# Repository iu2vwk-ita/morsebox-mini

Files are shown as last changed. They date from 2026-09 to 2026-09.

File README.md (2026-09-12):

# MorseBox Mini — WiFi CW Trainer

A Morse keyer in a box. It serves a web page over its own WiFi: join the
network, open the page, key with a real paddle or the touch paddle on screen,
and read back your keying as text. The sidetone comes straight off the GPIO
pins with zero lag, on up to three piezo buzzers at once.

Two builds, **the same features and the same web UI**:

| Build | Folder | Board | Display |
|---|---|---|---|
| **Raspberry Pi** | root (`server.py`, `install.sh`, …) | Pi 4 / 5 / Zero 2 W | MAX7219 8x8 (optional) |
| **ESP32 / MicroPython** | [`esp32/`](esp32/) | classic ESP32 (also C3/C6/S3 with small pin changes) | SSD1306 OLED or LCD1602 I2C (optional) |

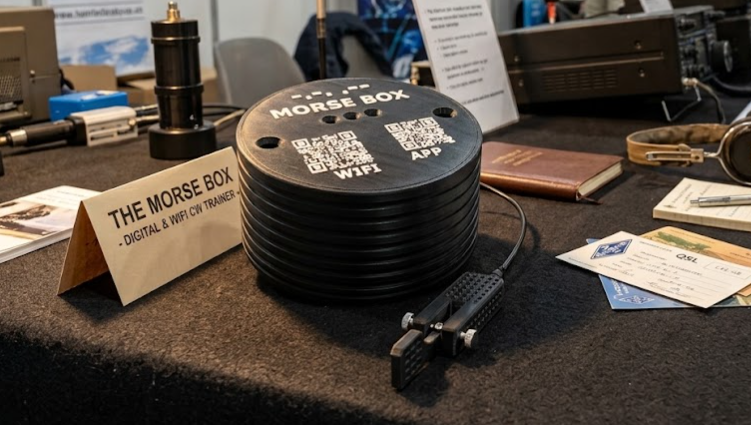
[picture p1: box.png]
MorseBox assembled


## Quick install

**Raspberry Pi** (Raspberry Pi OS) — one command:

```bash
sudo apt install -y git && git clone https://github.com/iu2vwk-ita/morsebox-mini.git morsebox && cd morsebox && sudo bash install.sh
```

**ESP32 / MicroPython** — one command (first: `pip install mpremote`):

```bash
git clone https://github.com/iu2vwk-ita/morsebox-mini.git && cd morsebox/esp32 && bash deploy.sh
```

## What it does

* Iambic A / B, straight key and a **SINGLE** beginner mode (one tap = one
  element, no memory/repeat), 5 to 60 WPM, paddle reverse (DX⇄SX)
* Live decoded text on the web page and on the display
* Sidetone pitch (500–1000 Hz) and volume from the page, on 1 to 3 piezos;
  **Active / Passive buzzer** selector (active buzzer or passive piezo)
* Key with a paddle, a straight key, the on-screen paddle, or the keyboard
  (`Z` / `X` / space)
* **Exercise mode / CW courses** — a built-in trainer (see below)
* **Reflex Trainer game** — 40 random characters, adaptive speed, countdown
  timer (menu item 1)

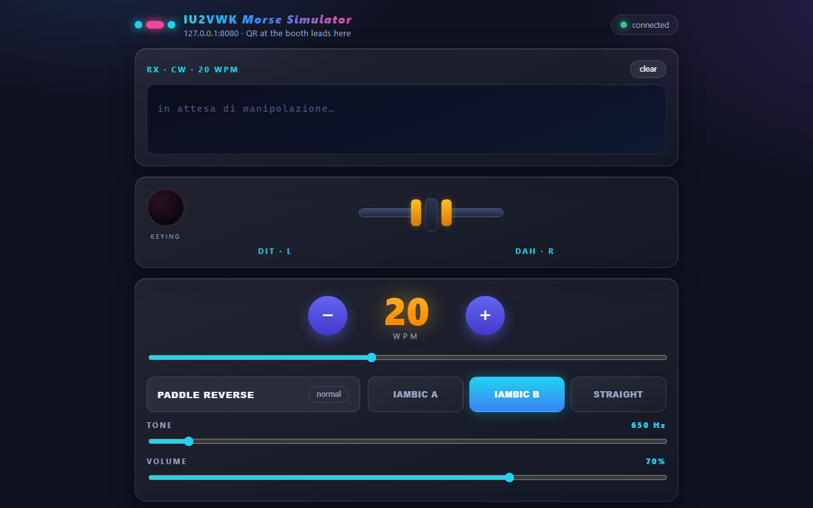
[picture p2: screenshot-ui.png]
Web UI


## Exercise mode (CW courses)

A guided trainer, available on **both** builds. Open the menu by keying **SOS**,
pick a drill with **N dots**, then confirm with **`..`** (or exit with `--`).
The target is **shown on the display and played on the piezo** at the chosen
WPM; for multi-letter targets the whole word is shown and the letter to key
**blinks**. A correct letter **flashes** as confirmation.

| N dots | Name on LCD | What |
|---|---|---|
| `.` | GAME | Reflex Trainer (see below) |
| `..` | ALPHABET | Alphabet A-Z |
| `...` | NUMBERS | Numbers 0-9 |
| `....` | KOCH | Koch order |
| `.....` | LETTERS | 20 random letters |
| `......` | DIGITS | 20 random digits |
| `.......` | MIXED | 20 random mixed letters/digits |
| `........` | CALLSIGNS | Common callsigns |
| `.........` | ABBREV | Q-codes / abbreviations |
| `..........` | PUNCT | Punctuation / prosigns |
| `-` | FULL | Full drill: A-Z then 0-9 |

While you key the menu selection the keyer runs slowly (**10 WPM**) so the dots
are easy to count; once a drill starts it uses your normal WPM setting. When you
pick a number the display shows its name (e.g. `4 KOCH ?`) before you confirm
with `..`, so the mapping is always visible on the device.

### Reflex Trainer (game)

Key **`SOS`** then **one dot** (or key the word `GAME`) to play. The box plays a
random character and you key it back before the timer bar runs out:

* correct -> **+1 point**, speed **+1 WPM**
* wrong or too slow -> **lose a life**, speed **-2 WPM**

It adapts to your level (10-40 WPM). You start with 3 lives; the display shows
`S:score L:lives WPM` and the countdown bar. Key **6 dots** to stop.

During a drill: **`......`** (6 dots, one group) = **stop**,
**`------`** (6 dashes, one group) = **skip**. A correct answer advances, a
wrong one restarts the target; the run ends with `DONE n/m`. You can also start
directly with `TEST` (full drill) or `TEST1`..`TEST9`.

## Open the web UI

The board is the access point. No home router, no internet needed.

1. Power the box, wait a few seconds
2. Join the WiFi **`IU2VWK-MORSE`** (password `morse1234`). The phone will say
   "connected without internet": that is normal, stay on it
3. Open **`http://10.42.0.1`**

The lid has two QR codes: **WIFI** joins the network, **APP** opens the page.
At home the Raspberry Pi version also works over Ethernet on port 80.

## Raspberry Pi — hardware and wiring

* Raspberry Pi (4, 5, Zero 2 W or similar) with Raspberry Pi OS Lite
* Paddle or straight key wired to the GPIO header (contacts to GND, internal
  pull-ups, no extra parts)
* 1 to 3 passive piezo buzzers (KY-006 3-pin modules)
* Optional MAX7219 8x8 LED matrix (shows WPM plus live decoded text)

| Function | BCM GPIO | Header pin |
|---|---|---|
| DIT (paddle) | 17 | 11 |
| DAH (paddle) | 27 | 13 |
| Straight key | 22 | 15 |
| GND | — | 6, 9, 14… |
| Piezo 1 signal | 24 | 18 |
| Piezo 2 signal | 25 | 22 |
| Piezo 3 signal | 12 | 32 |
| MAX7219 DIN / CLK / CS | 10 / 11 / 8 | 19 / 23 / 24 |

Each KY-006 module: `S` to its signal pin, `+` (middle) to 5V, `−` to GND. All
`5V` pins are one rail and all `GND` pins are one rail, so power wires can
share. Default buzzer mode is `passive`; with a self-beeping active buzzer use
`--buzzer-mode active`.

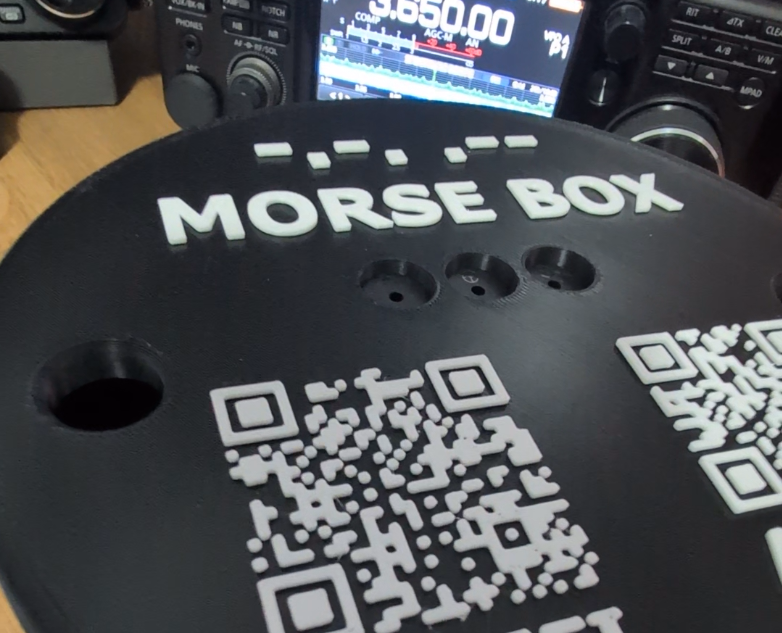
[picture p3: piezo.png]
The three piezos wired in


Install (the one-liner above does all of this): it sets the hostname to
`iu2vwk-morse`, installs the autostart service and brings up the
`IU2VWK-MORSE` access point. Three buzzers:

```bash
# /etc/systemd/system/iu2vwk-morse.service
ExecStart=/usr/bin/python3 /opt/iu2vwk-morse/server.py --port 80 --buzz-pins 24,25,12
sudo systemctl daemon-reload && sudo systemctl restart iu2vwk-morse
```

## ESP32 / MicroPython — hardware and wiring

Code in [`esp32/`](esp32/), full guide in
[`esp32/README-ESP32.md`](esp32/README-ESP32.md) (flashing, LCD1602, wiring).

| Function | GPIO |
|---|---|
| DIT | 32 |
| DAH | 33 |
| STRAIGHT | 14 |
| PIEZO 1 / 2 / 3 | 25 / 26 / 27 |
| I2C SDA / SCL (OLED or LCD1602) | 21 / 22 |
| MAX7219 SCK / MOSI / CS | 18 / 23 / 4 |

Key contacts to GND, internal pull-ups. The firmware auto-detects the display
at boot: **SSD1306 OLED first, then LCD1602, then MAX7219, then none**. Both
I2C displays share the same two wires:

* **SSD1306 OLED** (0.96"/1.3", 128x64, I2C 4-pin) — the nicest option: ~5-6
  lines of text, no cramped 16x2 window. `VCC` to **3.3V**, `GND`, `SCL` to
  GPIO22, `SDA` to GPIO21. Address 0x3C/0x3D (auto-detected).
* **LCD1602** with I2C backpack — `VCC` to 5V (VIN), `GND`, same SDA/SCL.
  Address 0x27/0x3F.

### Display options (pick one, or none)

The firmware detects the display automatically, in this order:
**SSD1306 OLED -> LCD1602 -> MAX7219 -> no display**. Nothing to configure.

* **With SSD1306 OLED** (recommended — "the nice one") — 128x64 graphical
  display, same two I2C wires as the LCD. Top line `WPM xx` + keyer mode, then
  the decoded text wrapped over several lines; the exercise target and its `^`
  cursor are far easier to read. The driver is loaded **only** if the I2C bus
  answers at 0x3C/0x3D, so with no OLED there is no RAM cost.

* **With LCD1602** — line 1 `WPM xx` + keyer mode, line 2 the decoded text.

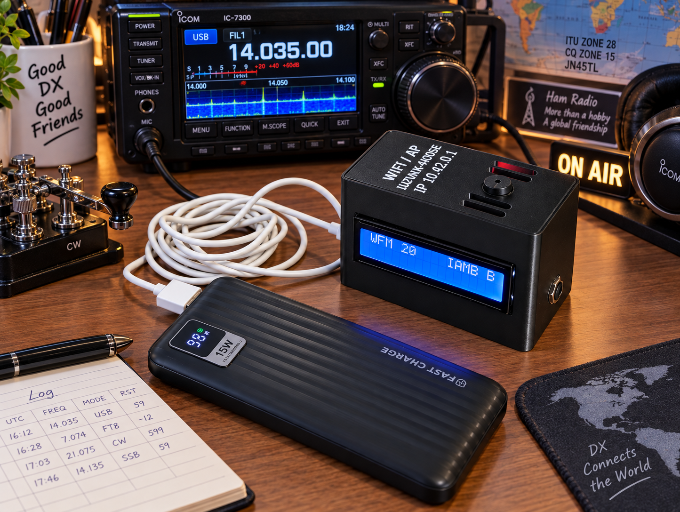
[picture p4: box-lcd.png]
MorseBox ESP32 with LCD1602
  

* **Without display (simpler)** — no display: everything is controlled from the
  phone web app (speed, mode, tone, volume and the decoded text). This is the
  easiest build.

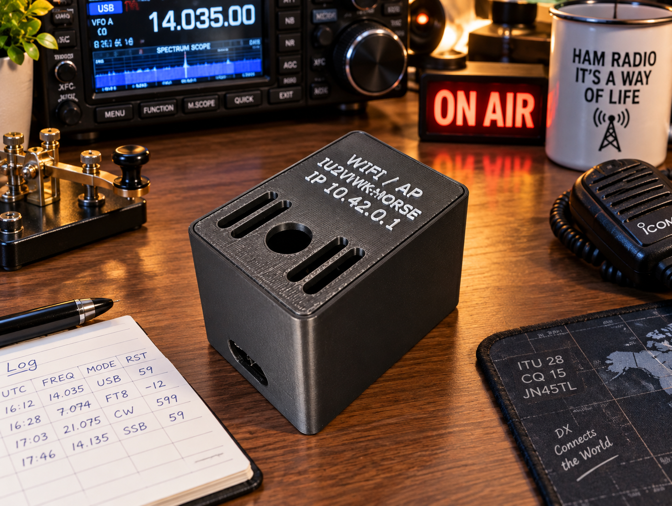
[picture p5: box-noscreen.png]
MorseBox ESP32 without LCD
  

## Box and fair material

* `qr-1-wifi.png` / `qr-2-pagina.png` — the **WIFI** and **APP** QR codes for
  the lid
* `qr-1-wifi.dxf` / `qr-2-pagina.dxf` — same QRs as 2 mm geometry for laser
  engraving in Autodesk Inventor
* `screenshot-ui-phone.png` — how the page looks on a phone
* `CW BOX SMALL.3mf` — the box, ready to 3D print, all versions on separate
  plates: ESP32 with LCD, ESP32 without LCD, and Raspberry Pi

73 de IU2VWK · Angelo — https://iu2vwk.com

Thanks to Panko for the inspiration and the original
[Simple CW Keyer](https://github.com/Panko74/Simple-CW-Keyer).

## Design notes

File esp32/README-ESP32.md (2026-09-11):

# MorseBox Mini - ESP32 / MicroPython version

Port of the Raspberry Pi version to a classic **ESP32** with **MicroPython**.
The web UI is **identical** to the Pi one: the same `static/index.html`,
`static/style.css`, `static/app.js` files are served unchanged, and the
WebSocket protocol is the same.

## What it does

- The ESP32 creates the access point **`IU2VWK-MORSE`** (password `morse1234`).
- HTTP + WebSocket web server on port **80**, IP **10.42.0.1**
  (same IP as the Pi: the lid QR codes keep working).
- Iambic A / B + straight keyer + **SINGLE** beginner mode (one tap = one
  element, no memory/repeat), 5-60 WPM, reverse DX/SX, CW to text decoder.
- **Zero-latency hardware PWM sidetone** on 1-3 piezos, no audio pipeline.
- Optional display, **auto-detected at boot**: SSD1306 OLED -> LCD1602 I2C ->
  MAX7219 8x8 -> none. The **OLED** (128x64, recommended) shows `WPM xx` +
  keyer mode on the top line and the decoded CW text wrapped below; the LCD
  shows 16x2. No RAM cost when no OLED is connected.

## Exercise mode

**Beginner-friendly start:** key **`SOS`** (`...---...`) to open the exercise
menu, key **N dots** to pick a drill, then **`..`** to confirm (or **`--`** to
exit). The target is **shown on the LCD and played on the piezo** (always
together) at the selected WPM, then you key it back.

| N dots | Name on LCD | Exercise |
|---|---|---|
| `.` | GAME | Reflex Trainer (see below) |
| `..` | ALPHABET | TEST1 - Alphabet A-Z |
| `...` | NUMBERS | TEST2 - Numbers 0-9 |
| `....` | KOCH | TEST3 - Koch order |
| `.....` | LETTERS | TEST4 - 20 random letters |
| `......` | DIGITS | TEST5 - 20 random digits |
| `.......` | MIXED | TEST6 - 20 random mixed |
| `........` | CALLSIGNS | TEST7 - Common callsigns |
| `.........` | ABBREV | TEST8 - Q-codes / abbreviations |
| `..........` | PUNCT | TEST9 - Punctuation / prosigns |
| `-` | FULL | Full drill: A-Z then 0-9 |

While you key the menu selection the keyer runs slowly (**10 WPM**,
`config.MENU_WPM`) so the dots are easy to count; once a drill starts it uses
the normal WPM setting. When you pick a number the LCD shows its name (e.g.
`4 KOCH ?`) before you confirm with `..`.

### Reflex Trainer (game)

Key **`SOS`** then **one dot** (or key `GAME`) to play. A random character is
played and you key it back before the timer bar runs out: correct = +1 point
and +1 WPM, wrong/too slow = -1 life and -2 WPM (10-40 WPM, 3 lives). The LCD
shows `S:score L:lives WPM` and the countdown bar. Key **6 dots** to stop.

You can also key **`TEST`** (full drill) or **`TEST1`..`TEST9`** directly.

Controls: **`......`** (6 dots) = stop, **`------`** (6 dashes) = skip. A
correct answer advances; a wrong one repeats the same target. The end of the
run shows `DONE n/m`.

## Pinout

| Function | GPIO | Mode |
|---|---|---|
| DIT | 32 | `Pin.IN, PULL_UP` (contact to GND) |
| DAH | 33 | `Pin.IN, PULL_UP` (contact to GND) |
| STRAIGHT | 14 | `Pin.IN, PULL_UP` (contact to GND) |
| PIEZO 1 | 25 | `machine.PWM` |
| PIEZO 2 | 26 | `machine.PWM` |
| PIEZO 3 | 27 | `machine.PWM` |
| MAX7219 SCK | 18 | hardware SPI VSPI |
| MAX7219 MOSI | 23 | hardware SPI VSPI |
| MAX7219 CS | 4 | output |
| I2C SDA (OLED / LCD1602) | 21 | I2C |
| I2C SCL (OLED / LCD1602) | 22 | I2C |

The three piezos sound together: even one is enough.
The key contacts go to GND; the pull-ups are internal to the ESP32.

**Display** (optional, auto-detected: **OLED -> LCD1602 -> MAX7219 -> none**).
Both I2C displays use the same two wires:

- **SSD1306 OLED** (0.96"/1.3", 128x64, I2C **4-pin**): `VCC` to **3.3V**,
  `GND`, `SCL` to GPIO22, `SDA` to GPIO21. Address 0x3C/0x3D, scanned
  automatically. This is the nicest option.
- **LCD1602** with I2C backpack: `VCC` to 5V (VIN), `GND`, same SDA/SCL
  (address 0x27/0x3F).

## Requirements

- ESP32 (WROOM-32) with recent MicroPython firmware (>= 1.20).
- `mpremote` on the PC: `pip install mpremote`.

If the ESP32 has no MicroPython, flash it with esptool:

```bash
esptool.py --chip esp32 --port /dev/ttyUSB0 erase_flash
esptool.py --chip esp32 --port /dev/ttyUSB0 write_flash -z 0x1000 \
  ESP32_GENERIC-20240602-v1.23.0.bin
```

## Deploy

```bash
bash deploy.sh                 # auto port
bash deploy.sh /dev/ttyUSB0    # explicit port
```

The script copies the `.py` files to the ESP32 root, creates `/static` with the
web UI and resets the board. On boot `main.py` starts.

## Test (no hardware)

The logic can be verified on a PC with CPython, using `uasyncio`/`time` stubs:

```bash
python3 tests/test_all.py
```

It covers: iambic A/B keyer, single mode, reverse, straight, decoder, WebSocket handshake,
frame encode/decode, HTTP parsing, routes and path traversal.

## Usage

1. Power the board, wait a few seconds.
2. On your phone, join the Wi-Fi **`IU2VWK-MORSE`** (password `morse1234`).
   The phone will say "no internet": that is normal, stay on that network.
3. Open **`http://10.42.0.1`**.
4. Key with the paddle, the straight key, the touch paddles or the keyboard
   (`Z` / `X` / space bar).

## Configuration

In `config.py`:

- `OLED_ENABLED = True` to use an SSD1306 I2C OLED (default `True`, tried
  first). The `oled` module is imported only if the bus answers at 0x3C/0x3D,
  so there is **no RAM cost** when no OLED is connected.
- `LCD_ENABLED = True` to use the LCD1602 I2C display (default `True`).
- `DISPLAY_ENABLED = True` to use the MAX7219 matrix (default `False`).
- `BUZZER_MODE = "passive"` for piezos (default). `"active"` for buzzers with
  a built-in oscillator (DC on/off drive).
- `AP_SSID` / `AP_PASS` / `AP_IP` to change the network.

The WPM, tone, volume, mode and reverse settings are saved in `settings.json`
and persist across reboots.

## Module reference

| Module | Main entry points | What it does |
|---|---|---|
| `main.py` | `main()` | Boot: AP, settings, paddle, piezo, display, event loop |
| `config.py` | constants | Pin map, defaults, boot messages |
| `wifi_ap.py` | `start_ap()` | Creates the `IU2VWK-MORSE` access point |
| `gpio.py` | `Paddle.read()` | Reads DIT / DAH / STRAIGHT (active low, pull-up) |
| `sidetone.py` | `Sidetone.set()`, `set_freq()`, `set_volume()` | Zero-latency PWM on 1-3 piezos |
| `keyer.py` | `Keyer.run()` | Iambic A/B + straight + single state machine and CW decoder |
| `keyer.py` | `_set_key()`, `_flush_letter()`, `_check_exercise_trigger()`, `_menu_select()` | Key output, letter decoding, exercise triggers and menu |
| `exercise.py` | `build(n)` | Builds the target list for drill `n` (0..9) |
| `exercise.py` | `Exercise.enter_menu()`, `select()`, `confirm()`, `cancel()`, `start()`, `feed()`, `run()` | Menu, confirmation, per-letter progress, blinking target, playback |
| `reflex.py` | `Reflex.run()`, `start()`, `feed()` | Reflex Trainer game: random target, countdown timer, adaptive WPM |
| `hub.py` | `Hub.broadcast()`, `remote()`, `hold()` | WebSocket clients, remote paddle holds, text history |
| `wsproto.py` | `ws_accept()`, `ws_encode()`, `ws_read_frame()` | Minimal RFC 6455 WebSocket |
| `webserver.py` | `WebServer.start()` | HTTP routes + WebSocket upgrade (native sockets) |
| `oled.py` | `Screen` | SSD1306 128x64 OLED: WPM/mode, wrapped decoded text, exercise target |
| `ssd1306.py` | `SSD1306_I2C` | MicroPython SSD1306 I2C driver (micropython-lib, MIT) |
| `lcd1602.py` | `I2cLcd`, `Screen` | 16x2 I2C display: WPM/mode, decoded text, exercise target |
| `display.py` | `Max7219`, `Screen` | Optional 8x8 matrix (scrolling text) |
| `settings.py` | `Settings.get()`, `patch()` | Persistent settings on `settings.json` |
| `morse.py` | `MORSE`, `FROM_MORSE` | Morse table and its reverse |
| `tests/test_all.py` | — | Host-side tests (CPython, `uasyncio`/`time`/`machine`/`ssd1306` stubs) |
| `tests/selftest_device.py` | — | On-device self-test: AP, GPIO, PWM, HTTP, WS, keyer |

## Differences from the Pi version

| | Raspberry Pi | ESP32 MicroPython |
|---|---|---|
| Concurrency | threads | single `uasyncio` event loop |
| Web server | `http.server` + custom WS | native `uasyncio` sockets + custom WS |
| AP | hostapd + dnsmasq | native `network.WLAN(AP_IF)` |
| AP IP | 10.42.0.1 | 10.42.0.1 |
| mDNS hostname | `iu2vwk-morse.local` | not available (use the IP) |
| Deploy | `install.sh` + systemd | `deploy.sh` + `main.py` |
| Mic audio decoder | yes (optional) | **no** (dropped) |

## Technical notes

- The keyer runs at a ~1 ms tick and uses `time.ticks_ms()`: loop jitter does
  not accumulate, because every element is computed from the current instant.
- The sidetone is switched directly by the key state through `machine.PWM`:
  no audio buffer, no perceivable delay.
- `hub.broadcast()` never blocks the keyer: every WebSocket client has a queue;
  a slow client is dropped without stopping the key.

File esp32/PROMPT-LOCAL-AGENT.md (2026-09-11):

# Prompt to paste into a local AI agent (with filesystem and USB access)

You are an AI agent with access to this PC's filesystem and USB ports.
You must install MicroPython on an ESP32 board connected over USB, upload the
project inside `morsebox-esp32.zip` and run the automated tests.
Do not ask for confirmation for the commands: run them and report the result.
If a command fails, diagnose it and try the suggested alternatives.

## Project

- Folder `morsebox-esp32/` (inside the zip).
- MicroPython app: on boot `main.py` creates the access point
  **`IU2VWK-MORSE`** (password `morse1234`), IP **10.42.0.1**, web server on
  port **80**.
- Pinout: **DIT=GPIO32**, **DAH=GPIO33**, **STRAIGHT=GPIO14** (all `Pin.IN`
  with `PULL_UP`, contacts to GND); **PIEZO=GPIO25,26,27** (PWM); MAX7219
  optional on **SCK=18, MOSI=23, CS=4** (disabled by default); LCD1602 I2C on
  **SDA=21, SCL=22**.
- `static/` is the web UI: **do not modify it**.
- `tests/selftest_device.py` is the test that runs **on the board**.

## Phase 0 - extract and prepare the tools

```bash
unzip morsebox-esp32.zip
cd morsebox-esp32
python3 -m venv .venv && . .venv/bin/activate
pip install esptool mpremote
```

## Phase 1 - detect serial port and chip

```bash
# Linux
ls /dev/ttyUSB* /dev/ttyACM*
# macOS
ls /dev/cu.*
# detect the chip (replace <PORT>)
esptool.py --port <PORT> chip_id
```

If no port appears: change the cable (it must be a **data** cable, not
charge-only), try another USB port, or use a USB-TTL adapter on TX/RX/GND.
On Linux, if permission is denied: `sudo chmod a+rw <PORT>` or add the user to
the `dialout` group.

## Phase 2 - flash MicroPython

Pick the firmware based on the detected chip:

- Classic ESP32 -> `ESP32_GENERIC`
- ESP32-S3 -> `ESP32_GENERIC_S3`
- ESP32-C3 -> `ESP32_GENERIC_C3`

Download the latest `.bin` from <https://micropython.org/download/> and then:

```bash
esptool.py --chip esp32 --port <PORT> erase_flash
esptool.py --chip esp32 --port <PORT> --baud 460800 write_flash -z 0x1000 <firmware>.bin
```

If flashing fails, hold **BOOT** while connecting the board and retry.
Adapt `--chip` to the real chip (`esp32`, `esp32s3`, `esp32c3`).

## Phase 3 - deploy the project

```bash
bash deploy.sh <PORT>
```

Check the board contents:

```bash
mpremote connect <PORT> fs ls
mpremote connect <PORT> fs ls :static
```

## Phase 4 - on-device self-test

Disable autostart (so the REPL and port 80 are free), run the test, then
restore `main.py`:

```bash
mpremote connect <PORT> fs cp main.py :main.py.bak
mpremote connect <PORT> fs rm :main.py
mpremote connect <PORT> reset
sleep 3
mpremote connect <PORT> run tests/selftest_device.py
mpremote connect <PORT> fs cp main.py.bak :main.py
mpremote connect <PORT> fs rm :main.py.bak
mpremote connect <PORT> reset
```

Expect a sequence of `PASS` lines and at the end:

```
PASS: N   FAIL: 0
```

The test checks: AP active and IP `10.42.0.1`, GPIO read at idle, PWM on/off
and frequency, HTTP (`/`, `/style.css`, `/app.js`, `/api/settings`, 404),
WebSocket (101 + `hello`) and **Morse decoding driven by remote paddles**
(dit + dah -> `A`).

## Phase 5 - final report

Report concisely:

- serial port used and detected chip;
- MicroPython firmware used;
- full self-test output;
- any `FAIL` with its cause;
- confirmation that after the final reset the `IU2VWK-MORSE` AP is active.

## Success criteria

1. MicroPython installed and `main.py` restored (starts on boot).
2. Self-test with `FAIL: 0` (or every FAIL explained).
3. `IU2VWK-MORSE` AP active after the reset.

## What cannot be tested without hardware

- The physical paddle/straight key contacts and the real piezo sound.
- The MAX7219 display if not connected.

## Notes

- If the PC has no Wi-Fi it cannot join the AP: the self-test uses the board's
  own loopback (`127.0.0.1`), so it works anyway.
- Do not modify the files in `static/`: the UI must stay identical to the
  original.

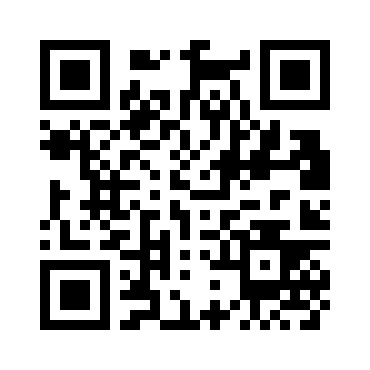
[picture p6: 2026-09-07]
qr-1-wifi.png

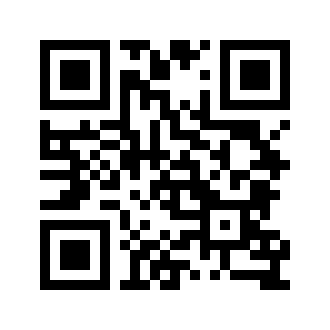
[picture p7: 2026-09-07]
qr-2-pagina.png

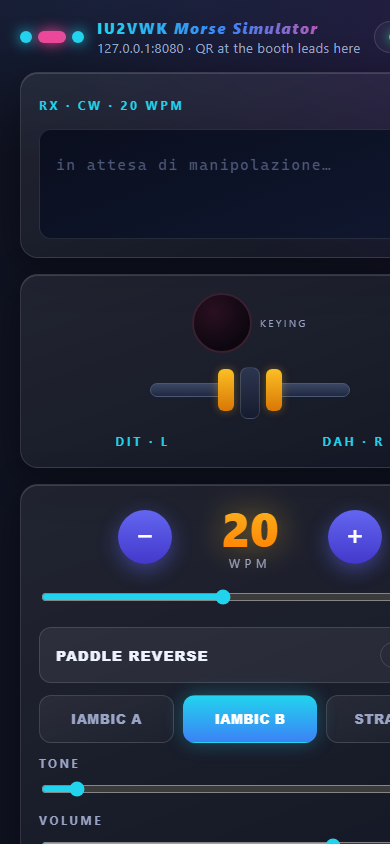
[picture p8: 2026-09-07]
screenshot-ui-phone.png

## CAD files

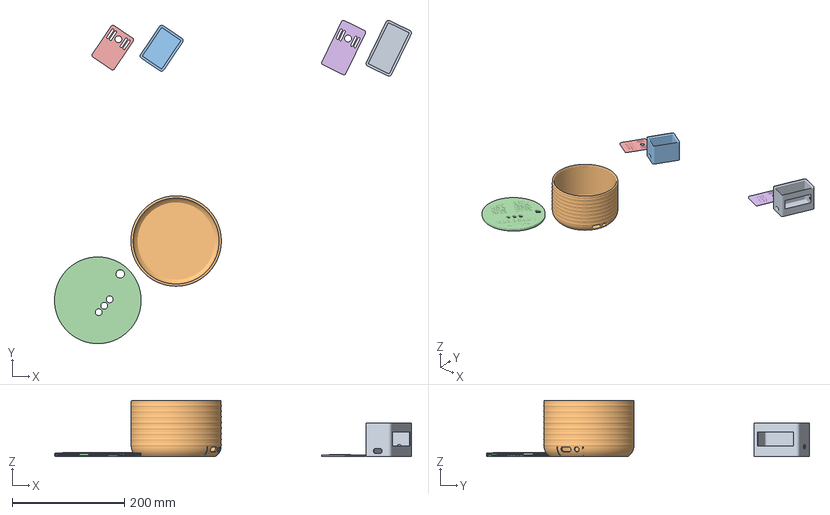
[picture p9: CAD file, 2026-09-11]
CW BOX SMALL.3mf
636.1 x 575.9 x 100.0 mm
cw box small sotto_CPY
cw box small sotto
cw box small coperchio
cw box small coperchio_CPY

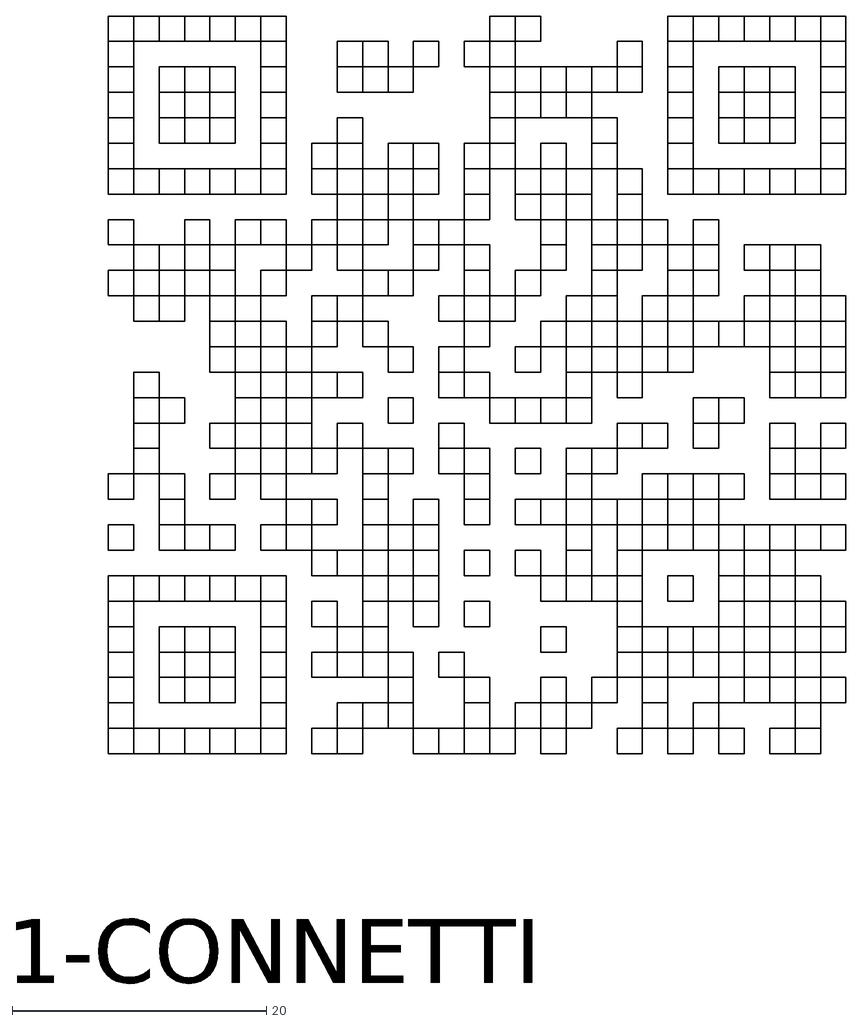
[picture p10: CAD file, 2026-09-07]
qr-1-wifi.dxf
1-CONNETTI

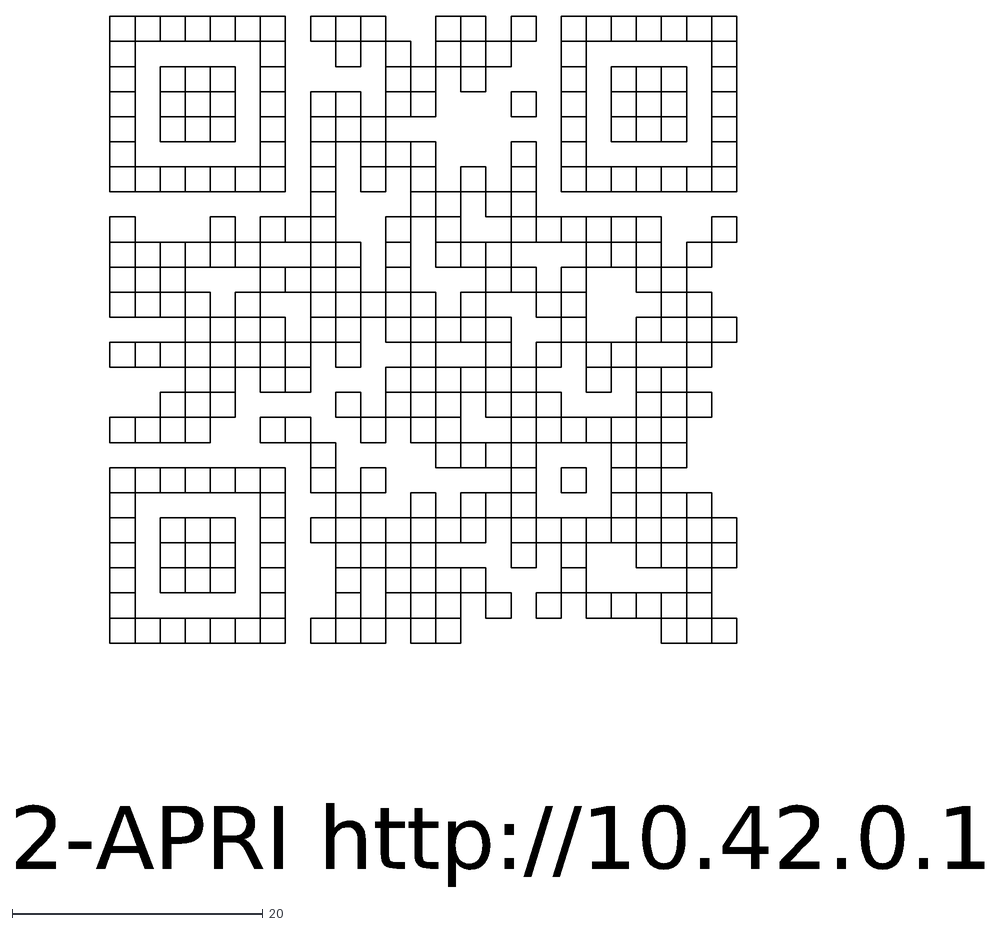
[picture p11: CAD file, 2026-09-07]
qr-2-pagina.dxf
2-APRI http://10.42.0.1

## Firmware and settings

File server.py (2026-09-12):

#!/usr/bin/env python3
"""IU2VWK Morse Simulator - iambic keyer + web UI for Raspberry Pi.

- Reads the paddle/straight key from the GPIO (mock fallback outside the Pi).
- Iambic A/B keyer + straight mode, 5-60 WPM, DX/SX swap.
- Serves the web UI, exposes a WebSocket for remote (touch) keys and live events.
- Decodes CW into text. Stdlib only: nothing to install.

Wiring (BCM): DIT=GPIO17 (pin 11), DAH=GPIO27 (pin 13), STRAIGHT=GPIO22 (pin 15),
GND on pin 6/9/14. Optional active buzzer on GPIO24 (pin 18). Contacts to GND.
"""
import argparse
import base64
import hashlib
import json
import os
import struct
import threading
import time
from http.server import BaseHTTPRequestHandler, ThreadingHTTPServer
from urllib.parse import urlparse
from morse import FROM_MORSE
from exercise import Exercise
from reflex import Reflex
from easter import EasterEgg

BASE_DIR = os.path.dirname(os.path.abspath(__file__))
SETTINGS_FILE = os.path.join(BASE_DIR, "settings.json")
STATIC_DIR = os.path.join(BASE_DIR, "static")

DEFAULTS = {"wpm": 20, "reverse": False, "mode": "iambic-b",
            "tone": 650, "buzzer": False, "volume": 70,
            "buzzer_mode": "passive"}

DIT_PIN, DAH_PIN, KEY_PIN, BUZZ_PIN = 17, 27, 22, 24
HOLD_TIMEOUT = 2.5  # s: forget remote paddles that stop reporting

# While choosing a program in the SOS menu (1-10 dots) the keyer runs slowly at
# this speed. Once the drill starts it uses the normal WPM setting.
MENU_WPM = 10

# ---------------------------------------------------------------- settings
def as_bool(v, default=False):
    """Strict boolean: 'false' must NOT become True (bool('false') == True)."""
    if isinstance(v, bool):
        return v
    if isinstance(v, (int, float)):
        return v != 0
    if isinstance(v, str):
        return v.strip().lower() in ("1", "true", "yes", "on")
    return default


class Settings:
    def __init__(self):
        self._lock = threading.Lock()
        self._data = dict(DEFAULTS)
        self._last_save = 0.0
        self._dirty = False
        try:
            with open(SETTINGS_FILE, encoding="utf-8") as f:
                self._data.update(json.load(f))
        except (OSError, ValueError):
            pass
        self._clamp()
        # flush debounced saves in the background (avoids SD wear on a drag)
        threading.Thread(target=self._saver, daemon=True).start()

    def _clamp(self):
        # per-field fallback: one bad value must not wipe the others
        d = self._data
        d["wpm"] = self._int(d, "wpm", 20, 5, 60)
        d["tone"] = self._int(d, "tone", 650, 500, 1000)
        d["volume"] = self._int(d, "volume", 70, 0, 100)
        d["reverse"] = as_bool(d.get("reverse", False))
        d["buzzer"] = as_bool(d.get("buzzer", False))
        if d.get("mode") not in ("iambic-a", "iambic-b", "straight", "single"):
            d["mode"] = "iambic-b"
        if d.get("buzzer_mode") not in ("active", "passive"):
            d["buzzer_mode"] = "passive"

    @staticmethod
    def _int(d, key, default, lo, hi):
        try:
            return max(lo, min(hi, int(d.get(key, default))))
        except (TypeError, ValueError):
            return default

    def get(self):
        with self._lock:
            return dict(self._data)

    def snapshot(self):
        """Read-only view with NO copy: used by the 1 ms keyer loop."""
        return self._data

    def patch(self, p):
        with self._lock:
            for k in DEFAULTS:
                if k in p:
                    self._data[k] = p[k]
            self._clamp()
            self._dirty = True
            data = dict(self._data)
        self.flush()
        return data

    def flush(self):
        """Write at most once per second; the background thread guarantees the
        last change is eventually persisted."""
        with self._lock:
            if not self._dirty:
                return
            now = time.monotonic()
            if now - self._last_save < 1.0:
                return
            self._last_save = now
            self._dirty = False
            data = dict(self._data)
        try:
            with open(SETTINGS_FILE, "w", encoding="utf-8") as f:
                json.dump(data, f)
        except OSError:
            with self._lock:
                self._dirty = True

    def _saver(self):
        while True:
            time.sleep(0.5)
            try:
                self.flush()
            except Exception:
                pass


# ---------------------------------------------------------------- gpio
class GPIO:
    """Active-low pull-up inputs. Tries RPi.GPIO, then gpiozero, then mock."""

    def __init__(self, buzz_pins=None):
        self.backend = "mock"
        self._gpio = None
        self._dit = self._dah = self._key = None
        self._buzz = []
        # Extra buzzer pins (BCM), e.g. [24, 25]. Default: only 24 (pin 18).
        self.buzz_pins = list(buzz_pins) if buzz_pins else [BUZZ_PIN]
        try:
            import RPi.GPIO as G
            G.setmode(G.BCM)
            for p in (DIT_PIN, DAH_PIN, KEY_PIN):
                G.setup(p, G.IN, pull_up_down=G.PUD_UP)
            self._gpio = G
            self.backend = "RPi.GPIO"
        except Exception:
            try:
                from gpiozero import Button, LED
                self._dit = Button(DIT_PIN, pull_up=True)
                self._dah = Button(DAH_PIN, pull_up=True)
                self._key = Button(KEY_PIN, pull_up=True)
                self._buzz = [LED(p) for p in self.buzz_pins]
                self.backend = "gpiozero"
            except Exception:
                pass

    def read(self):
        """(dit, dah, straight) True = pressed."""
        if self._gpio is not None:
            G = self._gpio
            return (not G.input(DIT_PIN), not G.input(DAH_PIN),
                    not G.input(KEY_PIN))
        if self._dit is not None:
            return (self._dit.is_pressed, self._dah.is_pressed,
                    self._key.is_pressed)
        return (False, False, False)

    def buzzer(self, on):
        try:
            if self._gpio is not None and self._buzz_pin_ready():
                self._gpio.output(self.buzz_pins, self._gpio.HIGH if on
                                  else self._gpio.LOW)
            elif self._buzz:
                for b in self._buzz:
                    b.on() if on else b.off()
        except Exception:
            pass

    def _buzz_pin_ready(self):
        if not getattr(self, "_buzz_setup", False):
            try:
                for p in self.buzz_pins:
                    self._gpio.setup(p, self._gpio.OUT,
                                     initial=self._gpio.LOW)
            except Exception:
                return False
            self._buzz_setup = True
        return True


# ---------------------------------------------------------------- keyer
class Hub:
    """Holds WS clients, remote holds and text history. Thread-safe."""

    def __init__(self):
        self._lock = threading.Lock()
        self.clients = set()
        self.holds = {}  # cid -> {"dit":b,"dah":b,"key":b,"ts":t}
        self.history = ""

    def add(self, c):
        with self._lock:
            self.clients.add(c)

    def drop(self, c):
        with self._lock:
            self.clients.discard(c)
            self.holds.pop(id(c), None)

    def hold(self, c, dit, dah, key):
        with self._lock:
            self.holds[id(c)] = {"dit": bool(dit), "dah": bool(dah),
                                 "key": bool(key), "ts": time.monotonic()}

    def remote(self):
        now = time.monotonic()
        d = h = k = False
        with self._lock:
            for cid in list(self.holds):
                v = self.holds[cid]
                if now - v["ts"] < HOLD_TIMEOUT:
                    d = d or v["dit"]
                    h = h or v["dah"]
                    k = k or v["key"]
                else:
                    del self.holds[cid]      # prune stale holds
        return d, h, k

    def push_text(self, ch):
        with self._lock:
            self.history = (self.history + ch)[-120:]

    def snapshot_text(self):
        with self._lock:
            return self.history

    def clear_text(self):
        with self._lock:
            self.history = ""

    def broadcast(self, msg, exclude=None):
        raw = json.dumps(msg)
        with self._lock:
            clients = list(self.clients)
        for c in clients:
            if c is exclude:
                continue
            try:
                c.send_text(raw)
            except Exception:
                self.drop(c)


class Keyer(threading.Thread):
    """Iambic keyer + decoder. 1 ms tick, events via hub.broadcast."""

    def __init__(self, gpio, settings, hub, exercise=None, reflex=None,
                 easter=None):
        super().__init__(daemon=True)
        self.gpio = gpio
        self.settings = settings
        self.hub = hub
        self.exercise = exercise
        self.reflex = reflex
        self.easter = easter
        self.key_out = False
        self._stop = threading.Event()
        self.screen = None  # matrix display (optional)
        self.sidetone = None  # note to the speaker (optional)

    def _set_key(self, on):
        if on == self.key_out:
            return
        self.key_out = on
        self.hub.broadcast({"t": "key", "on": on,
                            "dit": getattr(self, "_in_dit", False),
                            "dah": getattr(self, "_in_dah", False)})
        busy = ((self.exercise and self.exercise.playing)
                or (self.reflex and self.reflex.playing)
                or (self.easter and self.easter.playing))
        if self.sidetone and not busy:
            self.sidetone.set(on)
        now = time.monotonic()
        if on:
            self._on_at = now
        else:
            self._decode_element(now - self._on_at, self._unit)
            self._off_at = now

    def _decode_element(self, dur, unit):
        self._buf += "-" if dur >= 2 * unit else "."

    def _flush_letter(self):
        if self._buf:
            buf = self._buf
            ch = FROM_MORSE.get(buf, "◇")
            if self.exercise and self.exercise.active:
                # during an exercise the decoded letter is the answer
                self.exercise.feed(ch, buf)
            elif self.reflex and self.reflex.active:
                # during the Reflex game the decoded letter is the answer
                self.reflex.feed(ch, buf)
            elif self.easter and self.easter.playing:
                # 6 dots stop the easter-egg message early
                if buf and set(buf) == {"."} and len(buf) >= 6:
                    self.easter.stop()
            elif self.exercise and self.exercise.menu:
                self._menu_select(buf)
            elif self.exercise and buf == "...---...":
                # SOS keyed with no gaps: open the menu, do not print a symbol
                self.exercise.enter_menu()
            else:
                self.hub.push_text(ch)
                self.hub.broadcast({"t": "txt", "ch": ch})
                if self.screen:
                    self.screen.add_char(ch)
                self._check_exercise_trigger(buf)
            self._buf = ""

    def _menu_select(self, buf):
        """Menu: N dots = exercise N, one dash = full drill. Then confirm:
        .. = start, -- = exit."""
        ex = self.exercise
        if ex.pending is not None:
            if buf == "..":
                ex.confirm()
            else:
                ex.cancel()
            return
        if buf == "-":
            ex.select(0)              # full drill
        elif buf and set(buf) == {"."}:
            n = len(buf)
            if n == 1:
                # menu item 1: the Reflex game (not a drill)
                ex.cancel()
                if self.reflex:
                    self.reflex.start_game()
            elif 2 <= n <= 10:
                ex.select(n - 1)      # menu number -> drill number
            else:
                ex.cancel()
        else:
            ex.cancel()

    def _check_exercise_trigger(self, buf=None):
        """Start an exercise on SOS (menu) or TEST / TESTn."""
        txt = self.hub.snapshot_text().replace(" ", "").upper()
        if self.reflex and txt.endswith("GAME"):
            self.reflex.start_game()
            return
        if not self.exercise:
            return
        if buf == "...---...":
            self.exercise.enter_menu()
            return
        if txt.endswith("SOS"):
            self.exercise.enter_menu()
            return
        for n in range(9, 0, -1):
            if txt.endswith("TEST%d" % n):
                self.exercise.start_drill(n)
                return
        if txt.endswith("TEST"):
            self.exercise.start_drill(0)

    def run(self):
        dit_mem = dah_mem = False
        last = "dah"
        sending = None
        t_end = t_gap = 0.0
        self._buf = ""
        self._on_at = 0.0
        self._off_at = 0.0
        word_sent = True
        p_dit = p_dah = p_key = False
        prev_dit = prev_dah = False
        queue = []                 # single mode: pending taps
        self._pad_dit = self._pad_dah = False
        snap = getattr(self.settings, "snapshot", None) or self.settings.get
        while not self._stop.is_set():
            now = time.monotonic()
            st = snap()
            unit = 1.2 / st["wpm"]
            if self.exercise and self.exercise.menu:
                # while choosing a program the keyer runs slowly (MENU_WPM)
                unit = 1.2 / MENU_WPM
            elif self.reflex and self.reflex.active:
                # Reflex game: RX and TX share the same speed
                unit = 1.2 / max(1, self.reflex.wpm)
            self._unit = unit
            mode = st["mode"]
            rev = st["reverse"]

            pd, ph, pk = self.gpio.read()
            rd, rh, rk = self.hub.remote()
            # reverse: swap DIT/DAH on BOTH inputs (GPIO and touch)
            raw_dit = pd or rd
            raw_dah = ph or rh
            dit = raw_dah if rev else raw_dit
            dah = raw_dit if rev else raw_dah
            skey = pk or rk
            self._in_dit, self._in_dah = dit, dah
            if (dit, dah) != (self._pad_dit, self._pad_dah):
                self._pad_dit, self._pad_dah = dit, dah
                self.hub.broadcast({"t": "pad", "dit": dit, "dah": dah})

            # 5 ms debounce
            if (dit, dah, skey) != (p_dit, p_dah, p_key):
                p_dit, p_dah, p_key = dit, dah, skey
                time.sleep(0.002)
                continue

            if mode == "straight":
                dit_mem = dah_mem = False
                sending = None
                self._set_key(skey)
            elif mode == "single":
                # Beginner mode: one tap = exactly one element, no memory and
                # no automatic repeat. Taps are queued in press order.
                if dit and not prev_dit and len(queue) < 8:
                    queue.append("dit")
                if dah and not prev_dah and len(queue) < 8:
                    queue.append("dah")
                if sending is not None:
                    if now >= t_end:
                        self._set_key(False)
                        sending = None
                        t_gap = now + unit
                elif queue and now >= t_gap:
                    nxt = queue.pop(0)
                    sending, last = nxt, nxt
                    self._set_key(True)
                    t_end = now + (unit if nxt == "dit" else 3 * unit)
            else:
                # Memory: while in the gap any closed paddle is remembered;
                # while an element is playing only a NEW press counts (rising
                # edge). The old code re-latched the paddle generating the
                # current element, so a normal hold added an extra element
                # (e.g. .- came out as .-.-).
                if sending is None:
                    # Release grace: a small release overshoot past the element
                    # must not add an extra element (see esp32/keyer.py).
                    grace = now - t_end < unit / 2
                    if dit and not (last == "dit" and grace):
                        dit_mem = True
                    if dah and not (last == "dah" and grace):
                        dah_mem = True
                else:
                    if dit and not prev_dit:
                        dit_mem = True
                    if dah and not prev_dah:
                        dah_mem = True

                if sending is not None:
                    if now >= t_end:
                        # never latch the paddle that just sent this element
                        if last == "dit":
                            dit_mem = False
                        else:
                            dah_mem = False
                        if mode == "iambic-a":
                            if not dit:
                                dit_mem = False
                            if not dah:
                                dah_mem = False
                        self._set_key(False)
                        sending = None
                        t_gap = now + unit
                elif now >= t_gap:
                    if dit_mem and dah_mem:
                        nxt = "dah" if last == "dit" else "dit"
                    elif dit_mem:
                        nxt = "dit"
                    elif dah_mem:
                        nxt = "dah"
                    else:
                        nxt = None
                    if nxt:
                        if nxt == "dit":
                            dit_mem = False
                        else:
                            dah_mem = False
                        sending, last = nxt, nxt
                        self._set_key(True)
                        t_end = now + (unit if nxt == "dit" else 3 * unit)
            prev_dit, prev_dah = dit, dah

            # decoder: letter gap 3u, word gap 7u
            if self._buf and not self.key_out and now - self._off_at > 3 * unit:
                self._flush_letter()
                word_sent = False
            if (not self._buf and not word_sent and not self.key_out
                    and now - self._off_at > 7 * unit):
                self.hub.push_text(" ")
                self.hub.broadcast({"t": "txt", "ch": " "})
                if self.screen:
                    self.screen.add_char(" ")
                word_sent = True

            time.sleep(0.001)

    def stop(self):
        self._stop.set()


# ---------------------------------------------------------------- websocket
WS_MAGIC = "258EAFA5-E914-47DA-95CA-C5AB0DC85B11"


def ws_accept(key):
    return base64.b64encode(
        hashlib.sha1((key + WS_MAGIC).encode()).digest()).decode()


def ws_encode(text):
    raw = text.encode("utf-8")
    hdr = bytes([0x81])
    n = len(raw)
    if n < 126:
        hdr += struct.pack("!B", n)
    elif n < 65536:
        hdr += struct.pack("!BH", 126, n)
    else:
        hdr += struct.pack("!BQ", 127, n)
    return hdr + raw


def ws_decode_frame(sock):
    hdr = _recvn(sock, 2)
    b1, b2 = hdr[0], hdr[1]
    opcode = b1 & 0x0F
    masked = b2 & 0x80
    ln = b2 & 0x7F
    if ln == 126:
        ln = struct.unpack("!H", _recvn(sock, 2))[0]
    elif ln == 127:
        ln = struct.unpack("!Q", _recvn(sock, 8))[0]
    mask = _recvn(sock, 4) if masked else None
    payload = _recvn(sock, ln) if ln else b""
    if masked and payload:
        payload = bytes(c ^ mask[i % 4] for i, c in enumerate(payload))
    return opcode, payload


def _recvn(sock, n):
    buf = b""
    while len(buf) < n:
        chunk = sock.recv(n - len(buf))
        if not chunk:
            raise ConnectionError("ws closed")
        buf += chunk
    return buf


class WSConn:
    def __init__(self, sock):
        self.sock = sock
        self._lock = threading.Lock()

    def send_text(self, text):
        with self._lock:
            self.sock.sendall(ws_encode(text))

    def send_raw(self, raw):
        with self._lock:
            self.sock.sendall(raw)


# ---------------------------------------------------------------- http
MIME = {".html": "text/html; charset=utf-8",
        ".css": "text/css; charset=utf-8",
        ".js": "application/javascript; charset=utf-8",
        ".json": "application/json",
        ".png": "image/png", ".svg": "image/svg+xml"}
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

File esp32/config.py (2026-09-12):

# IU2VWK MorseBox Mini - ESP32 / MicroPython configuration
#
# Pin mapping chosen for a classic ESP32 (WROOM-32), avoiding:
#   6-11      -> SPI flash
#   34-39     -> input only, NO internal pull-up
#   0/2/12/15 -> strapping pins
#   1/3       -> UART0 (REPL serial)
#
# Paddle (contacts to GND, internal pull-up enabled, active low):
#   DIT      GPIO32
#   DAH      GPIO33
#   STRAIGHT GPIO14
#
# Piezo (hardware LEDC PWM, all driven together):
#   PIEZO1   GPIO25
#   PIEZO2   GPIO26
#   PIEZO3   GPIO27
#
# Optional MAX7219 display (hardware VSPI):
#   SCK      GPIO18
#   MOSI     GPIO23
#   CS       GPIO4

# ------------------------------------------------------------------ paddle
DIT_PIN = 32
DAH_PIN = 33
KEY_PIN = 14

# ------------------------------------------------------------------ piezo
BUZZ_PINS = (25, 26, 27)
BUZZER_MODE = "passive"          # "passive" = piezo PWM, "active" = DC on/off

# ------------------------------------------------------------------ MAX7219 display
DISPLAY_ENABLED = False          # True if the MAX7219 matrix is connected
DISPLAY_SCK = 18
DISPLAY_MOSI = 23
DISPLAY_CS = 4
DISPLAY_MODULES = 4              # 4 x 8x8 = 32 columns

# ------------------------------------------------------------------ LCD1602 I2C
LCD_ENABLED = True               # True if the LCD1602 with I2C backpack is connected
LCD_I2C_ID = 0
LCD_SDA = 21                     # GPIO21 -> SDA
LCD_SCL = 22                     # GPIO22 -> SCL
LCD_ADDR = 0x27                  # PCF8574T = 0x27, PCF8574A = 0x3F
LCD_COLS = 16
LCD_ROWS = 2

# ------------------------------------------------------------------ OLED SSD1306
# 0.96"/1.3" I2C OLED (128x64). Tried first; falls back to the LCD1602.
OLED_ENABLED = True              # True if an SSD1306 I2C OLED is connected
OLED_I2C_ID = 0
OLED_SDA = 21                    # same I2C bus as the LCD1602
OLED_SCL = 22
OLED_ADDR = 0x3C                 # 0x3C / 0x3D (auto-detected on the bus too)
OLED_WIDTH = 128
OLED_HEIGHT = 64

# ------------------------------------------------------------------ access point
AP_SSID = "IU2VWK-MORSE"
AP_PASS = "morse1234"
AP_IP = "10.42.0.1"              # same IP as the Pi: the lid QR codes stay valid
AP_NETMASK = "255.255.255.0"
AP_CHANNEL = 6
HTTP_PORT = 80

# ------------------------------------------------------------------ keyer
HOLD_TIMEOUT_MS = 2500           # forget remote paddles that stop reporting
SETTINGS_FILE = "settings.json"
TONE_MIN = 500                   # sidetone range (Hz)
TONE_MAX = 1000

# While choosing a program in the SOS menu (1-10 dots) the keyer runs slowly at
# this speed, so the selection is easy. Once the drill starts it uses the normal
# WPM setting (default 20, changeable from the web UI).
MENU_WPM = 10

# ------------------------------------------------------------------ boot message
# Scrolled on the LCD (or MAX7219) once at startup. Set to "" to disable.
BOOT_TITLE = ""                          # optional fixed first line
BOOT_MESSAGE = "IU2VWK MORSE BOX - batti SOS per iniziare"
BOOT_HELP = ""                           # optional second scrolled message
BOOT_SPEED_MS = 90                       # scroll step in ms (lower = faster)

DEFAULTS = {"wpm": 20, "reverse": False, "mode": "iambic-b",
            "tone": 650, "buzzer": False, "volume": 70,
            "buzzer_mode": BUZZER_MODE}

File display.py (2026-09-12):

#!/usr/bin/env python3
"""MAX7219 dot matrix display (8x8, chained) for the Morse Simulator.

- Software SPI (bit-bang) driver with RPi.GPIO/gpiozero: no dependencies.
- Outside the Pi (or without a matrix) it falls back to "ascii" mode: it prints
  the frames to stdout, so you can check font and layout even on Windows.
- The thread shows a scrolling line: "WPM xx" + last decoded text.

Wiring (BCM): DIN=GPIO10, CLK=GPIO11, CS=GPIO8, VCC=5V, GND=GND.
Chained modules: the next module's DIN goes to the previous one's DOUT.
"""
import threading
import time

DIN, CLK, CS = 10, 11, 8       # BCM (pin 19, 23, 24)
MODULES = 4                     # 4x 8x8 => 32 columns x 8 rows
INTENSITY = 8                   # 0..15

# 5x7 font, row oriented (7 bytes, bit0 = leftmost column, bit4 = right).
F = {
    " ": (0, 0, 0, 0, 0, 0, 0),
    "A": (0x0E, 0x11, 0x11, 0x1F, 0x11, 0x11, 0x11),
    "B": (0x1E, 0x11, 0x11, 0x1E, 0x11, 0x11, 0x1E),
    "C": (0x0E, 0x11, 0x10, 0x10, 0x10, 0x11, 0x0E),
    "D": (0x1E, 0x11, 0x11, 0x11, 0x11, 0x11, 0x1E),
    "E": (0x1F, 0x10, 0x10, 0x1E, 0x10, 0x10, 0x1F),
    "F": (0x1F, 0x10, 0x10, 0x1E, 0x10, 0x10, 0x10),
    "G": (0x0E, 0x11, 0x10, 0x17, 0x11, 0x11, 0x0F),
    "H": (0x11, 0x11, 0x11, 0x1F, 0x11, 0x11, 0x11),
    "I": (0x0E, 0x04, 0x04, 0x04, 0x04, 0x04, 0x0E),
    "J": (0x07, 0x02, 0x02, 0x02, 0x02, 0x12, 0x0C),
    "K": (0x11, 0x12, 0x14, 0x18, 0x14, 0x12, 0x11),
    "L": (0x10, 0x10, 0x10, 0x10, 0x10, 0x10, 0x1F),
    "M": (0x11, 0x1B, 0x15, 0x15, 0x11, 0x11, 0x11),
    "N": (0x11, 0x19, 0x15, 0x13, 0x11, 0x11, 0x11),
    "O": (0x0E, 0x11, 0x11, 0x11, 0x11, 0x11, 0x0E),
    "P": (0x1E, 0x11, 0x11, 0x1E, 0x10, 0x10, 0x10),
    "Q": (0x0E, 0x11, 0x11, 0x11, 0x15, 0x12, 0x0D),
    "R": (0x1E, 0x11, 0x11, 0x1E, 0x14, 0x12, 0x11),
    "S": (0x0F, 0x10, 0x10, 0x0E, 0x01, 0x01, 0x1E),
    "T": (0x1F, 0x04, 0x04, 0x04, 0x04, 0x04, 0x04),
    "U": (0x11, 0x11, 0x11, 0x11, 0x11, 0x11, 0x0E),
    "V": (0x11, 0x11, 0x11, 0x11, 0x11, 0x0A, 0x04),
    "W": (0x11, 0x11, 0x11, 0x15, 0x15, 0x1B, 0x11),
    "X": (0x11, 0x11, 0x0A, 0x04, 0x0A, 0x11, 0x11),
    "Y": (0x11, 0x11, 0x0A, 0x04, 0x04, 0x04, 0x04),
    "Z": (0x1F, 0x01, 0x02, 0x04, 0x08, 0x10, 0x1F),
    "0": (0x0E, 0x11, 0x13, 0x15, 0x19, 0x11, 0x0E),
    "1": (0x04, 0x0C, 0x04, 0x04, 0x04, 0x04, 0x0E),
    "2": (0x0E, 0x11, 0x01, 0x02, 0x04, 0x10, 0x1F),
    "3": (0x1F, 0x02, 0x04, 0x02, 0x01, 0x11, 0x0E),
    "4": (0x02, 0x06, 0x0A, 0x12, 0x1F, 0x02, 0x02),
    "5": (0x1F, 0x10, 0x1E, 0x01, 0x01, 0x11, 0x0E),
    "6": (0x06, 0x08, 0x10, 0x1E, 0x11, 0x11, 0x0E),
    "7": (0x1F, 0x01, 0x02, 0x04, 0x08, 0x08, 0x08),
    "8": (0x0E, 0x11, 0x11, 0x0E, 0x11, 0x11, 0x0E),
    "9": (0x0E, 0x11, 0x11, 0x0F, 0x01, 0x02, 0x0C),
    ".": (0, 0, 0, 0, 0, 0x0C, 0x0C),
    ",": (0, 0, 0, 0, 0x0C, 0x04, 0x08),
    "-": (0, 0, 0, 0x1F, 0, 0, 0),
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
}

COLUMNS = MODULES * 8


def glyph(ch):
    ch = ch.upper()
    return F.get(ch, F[" "])


class Raw7249:
    """Software SPI to one or more chained MAX7219 modules."""

    def __init__(self, modules=MODULES, intensity=INTENSITY):
        self.modules = modules
        self.g = self._open()
        if self.g is None:
            self.backend = "ascii"
        else:
            self.backend = "max7219"
            self._init(intensity)

    def _open(self):
        try:
            import RPi.GPIO as G
            G.setmode(G.BCM)
            for p in (DIN, CLK, CS):
                G.setup(p, G.OUT)
            G.output(DIN, 0), G.output(CLK, 0), G.output(CS, 1)
            self._G = G
            return "gpio"
        except Exception:
            try:
                from gpiozero import OutputDevice
                self._din = OutputDevice(DIN)
                self._clk = OutputDevice(CLK)
                self._cs = OutputDevice(CS, active_high=False)
                return "gpiozero"
            except Exception:
                return None

    def _bit(self, v):
        G = getattr(self, "_G", None)
        if G is not None:
            G.output(DIN, 1 if v else 0)
            G.output(CLK, 1)
            G.output(CLK, 0)
        else:
            self._din.value = 1 if v else 0
            self._clk.on()
            self._clk.off()

    def _latch(self):
        G = getattr(self, "_G", None)
        if G is not None:
            G.output(CS, 0)
            G.output(CS, 1)
        else:
            self._cs.on()  # active_high=False -> asserts the latch
            self._cs.off()

    def _write_cmd(self, reg, val):
        # 16 bit: [reg (8) | data (8)], MSB first, one module at a time
        frame = ((reg & 0x0F) << 8) | (val & 0xFF)
        for i in range(15, -1, -1):
            self._bit((frame >> i) & 1)

    def _send(self, reg, values):
        # values: one value per module (chain: first = last)
        for val in reversed(values):
            self._write_cmd(reg, val)
        self._latch()

    def _init(self, intensity):
        for reg, val in ((0x0C, 0x01), (0x0F, 0x00),   # normal, no test
                         (0x09, 0x00),                  # no decode
                         (0x0B, 0x07),                  # scan 8 rows
                         (0x0A, intensity),
                         (0x0C, 0x01)):                 # on
            self._send(reg, [val] * self.modules)

    def clear(self):
        for d in range(8):
            self._send(0x01 + d, [0] * self.modules)

    def write_rows(self, rows):
        # rows: list of 8 ints (one row per module? no: 8 total rows),
        # each int = bits per column (bit0 = module? handled by Screen)
        raise NotImplementedError

    def render(self, frame):
        """frame: list of COLUMNS ints, each = 8 bits per row (bit0=top).
        Writes row by row to the modules."""
        self.clear()
        for r in range(8):
            rowvals = []
            for m in range(self.modules):
                byte = 0
                for j in range(8):
                    col = m * 8 + j
                    if col < len(frame) and (frame[col] >> r) & 1:
                        byte |= 1 << (7 - j)   # bit7 = left column of the module
                rowvals.append(byte)
            self._send(0x01 + r, rowvals)
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

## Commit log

2026-09-07 MorseBox Mini: WiFi CW trainer with multi-piezo sidetone
    [qr-1-wifi.dxf, qr-2-pagina.dxf]
2026-09-07 Add 3MF box for 3D printing
    [Morse Code BOX.3mf]
2026-09-07 Update Morse Code BOX 3MF (rev 2)
    [Morse Code BOX.3mf]
2026-09-08 60 WPM web UI clamp
2026-09-08 60 WPM backend clamp
2026-09-11 Add ESP32/MicroPython port (esp32/), new CW BOX SMALL.3mf, keep Raspberry Pi version
    [CW BOX SMALL.3mf, Morse Code BOX.3mf]
2026-09-11 Add ESP32 LCD box photo (box-lcd.png)
2026-09-11 Add Quick install one-liners for Raspberry Pi and ESP32
2026-09-11 Replace 3mf with complete file (ESP32 with/without LCD + Raspberry Pi); update README
    [CW BOX SMALL.3mf]
2026-09-11 Web UI: ignore device echo while a slider is being moved (fix sliders jumping back)
2026-09-11 Web UI: send tone while dragging (fix tone not changing); ESP32: re-apply duty after freq change
    [sidetone.py]
2026-09-11 Boot: scroll a second message with test-mode controls (start/stop/skip)
    [config.py, display.py, lcd1602.py]
2026-09-11 Add exercise mode: TEST/TEST1..9, LCD+piezo together, 6 dots stop, 6 dashes skip
    [config.py, display.py, exercise.py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]
2026-09-11 Exercise: STOP/SKIP count dots/dashes across split groups
    [exercise.py, test_all.py]
2026-09-11 README: advertise the ESP32 exercise mode
2026-09-11 Exercise: show the target and blink the current letter to key
2026-09-11 README: add the exercise mode section with the full drill list
2026-09-11 Exercise: lighter LCD updates (line diff, slower blink) to stop keyer jitter
    [display.py, exercise.py, lcd1602.py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]
2026-09-11 Exercise: STOP/SKIP only as one 6+ group (no false exits), clear text on start, crash guard
    [exercise.py, hub.py, server.py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]
2026-09-11 LCD: force full redraw after the boot messages (was stuck on the last frame)
    [lcd1602.py]
2026-09-11 Exercise: replay the target when a letter is wrong
    [exercise.py]
2026-09-11 Fix exercise _tick indentation (dead code caused an infinite loop/freeze)
    [exercise.py, keyer.py, main.py]
2026-09-11 Exercise: remove blinking (caused I2C latency); static target display
2026-09-11 Exercise: LCD char-level diff (less I2C latency); remove debug print; log free RAM
2026-09-11 Sidetone: only apply freq on success + rebuild PWM fallback; debounce settings save
2026-09-11 Easter egg: reset the dot run at each letter gap (avoid false trigger)
    [keyer.py]
2026-09-11 Easter egg: fix text to KAPPAROGGERO POSITIVO
    [easter.py]
2026-09-11 Tone range 500-1000 Hz; do not echo settings back to the sender (fix volume slider)
    [config.py, hub.py, server.py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]
2026-09-11 Test: update tone clamp expectation to 500 Hz
2026-09-11 Fix tone-change lockup: keep PWM alive on freq fallback + never drop the WebSocket on a settings error
    [main.py, sidetone.py, test_all.py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]
2026-09-11 Clear button also wipes the physical screen (LCD/MAX7219) on Pi and ESP32
2026-09-11 Deep review fixes: word gap on display, no dict alloc in keyer loop, per-field settings clamp, strict bool, WS frame cap, exercise/Pi hardening
    [audio.py, display.py, easter.py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]
2026-09-11 Keyer: fix iambic memory re-latching the current element (dot-before-dash added an extra element)
    [keyer.py, server.py, test_all.py]
2026-09-11 Keyer: release grace + never latch the element's own paddle (fixes extra element on dot-before-dash)
    [keyer.py, server.py]
2026-09-11 Boot: short fast message (IU2VWK MORSE BOX - batti SOS per iniziare); exercise menu shows the drill name
    [config.py, display.py, exercise.py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]
2026-09-11 README: exercise menu shows drill names; document boot message
2026-09-11 Add Reflex Trainer game (menu item 1); menu selection at 10 WPM, drills at the user WPM
2026-09-11 Reflex game: 6 dots = STOP, 6 dashes = SKIP (like the exercises)
    [reflex.py, test_all.py]
2026-09-11 Easter egg: 2-line scrolling message explaining the box (replaces KAPPAROGGERO)
    [easter.py, test_all.py]
2026-09-11 Test: fix easter scroll window assertion
    [test_all.py]
2026-09-12 Add web UI buzzer selector (Active/Passive), persisted; sidetone.set_mode()
    [audio.py, config.py, main.py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]
2026-09-12 Active buzzer: gate the supply with a 20 kHz PWM so the volume slider works
    [sidetone.py, test_all.py]
2026-09-12 Pi: port Reflex game, easter egg and aligned menu; fix install.sh file list
    [display.py, easter.py, exercise.py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]
2026-09-12 Pi: fix Exercise/Reflex start() shadowing threading.Thread.start()
    [exercise.py, reflex.py, server.py]
